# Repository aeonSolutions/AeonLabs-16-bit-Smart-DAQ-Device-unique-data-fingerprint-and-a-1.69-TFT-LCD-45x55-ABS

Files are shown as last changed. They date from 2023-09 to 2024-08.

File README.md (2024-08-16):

<p align="center">
   
</p>


 
<a href="https://github.com/sponsors/aeonSolutions">
   
</a>

**Unique Visits** <a href="https://trackgit.com"> trackgit-views </a>



 
</p>

**Navigation** | [AeonLabs Main Index](https://github.com/aeonSolutions/aeonSolutions/blob/main/aeonSolutions-Main-Index.md)  >>   [open Hardware Electronics](https://github.com/aeonSolutions/PCB-Prototyping-Catalogue)  >>  [Laboratory Automation](https://github.com/aeonSolutions/PCB-Prototyping-Catalogue/tree/main/Laboratory%20Automation)  >> Smart DAQs   >> [16-bit Smart DAQs](https://github.com/aeonSolutions/PCB-Prototyping-Catalogue/blob/main/Smart%20DAQ/16-bit/readme.md)   >>  16-bit Smart DAQ Device with unique data fingerprint and a 1.69" TFT LCD 45x55 ABS

<p align="right">
 <a href="https://github-com.translate.goog/aeonSolutions/PCB-Prototyping-Catalogue/tree/main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">Change Language</a> <br>
Last update: 11-08-2024
</p>

# 16-bit Smart DAQ Device with unique data fingerprint and a 1.69" TFT LCD 45x55 ABS
This is the repository for the 16-bit Smart DAQ Device with a unique data fingerprint able to do experimental data upload to any data repository. This specific hardware electronics utilizes the ADC IC AD5693 from Analog Devices. More information about this ADC IC [here](https://www.analog.com/en/products/ad5693.html). 

<p align="center">
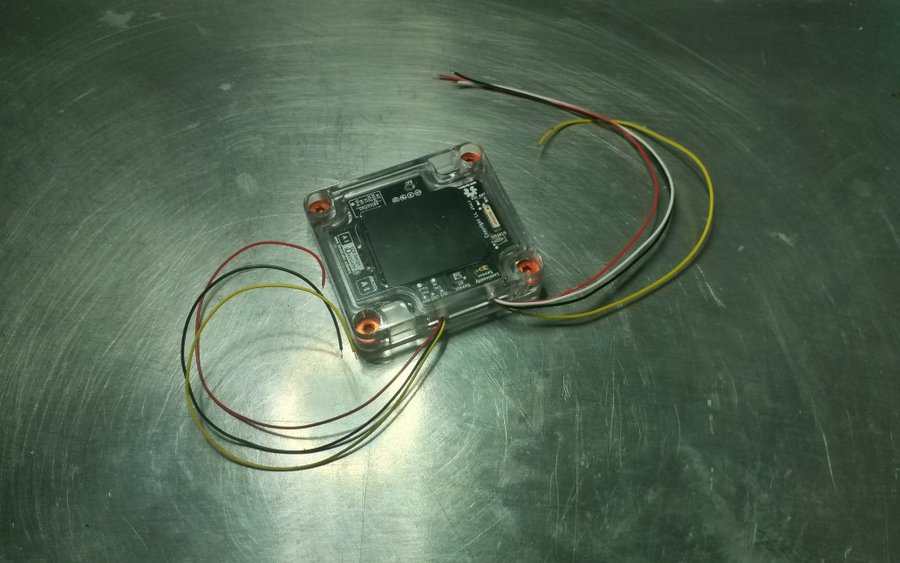
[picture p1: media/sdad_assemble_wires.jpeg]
   
</p>

<p align="center">
<strong> <a href="https://aeonsolutions.github.io/sponsor/sdad/2ch/">Interactive view of the PCB Layout</a> </strong> &nbsp;
  <strong> <a href="https://aeonsolutions.github.io/sponsor/sdad/2ch/circuit_schematic.html">Interactive view of the circuit schematic</a> </strong> <br>
 <sup>Click to view the latest revision</sup>
</p>

<br>

### rev. 10-2024
status: being designed in KiCad <br>
Known Issues: <br>
- ..

<p align="center">
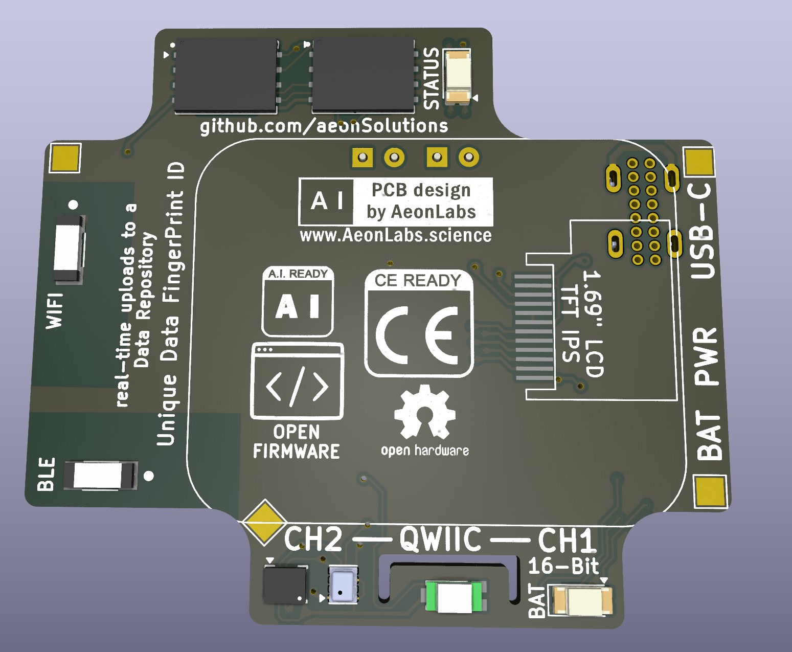
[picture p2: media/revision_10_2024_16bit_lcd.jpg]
    
</p>

<br>

### rev. 10-2023
status: Fully working <br>
Known Issues: <br>
- PCB copper track optimizations
- components rearrangement for optimization of PCB track inductance 

<p align="center">
    
</p>

### rev. 03-2024
This hardware electronics revision has major improvements in the power supply and  also power management improving immensely battery life. It also features USB-C to serial UART communications.

status: Fully working <br>
Known Issues: <br>
- PCB copper track optimizations
- components rearrangement for optimization of PCB track inductance
- poor design of the ground plane on the power management zone of the PCB
- The ultra-deep sleep power management does not work as intended. This is now solved in revision 05-2024.

<p align="center">
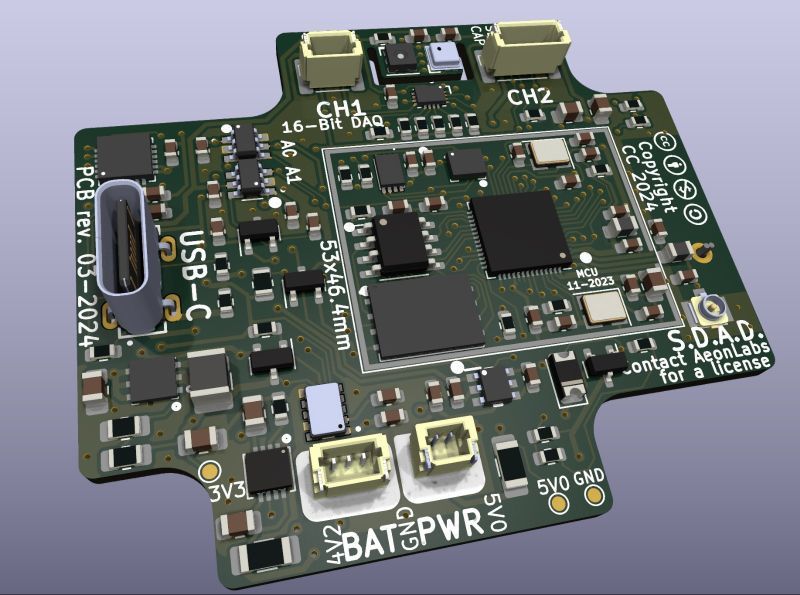
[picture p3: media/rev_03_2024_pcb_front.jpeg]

</p>

<br>
<br>

The photo below is one of the many specimens I purposely fabricated to research the self-sensing properties of asphalt mixed with a known content of carbon fibers. This is a 10cm cylinder specimen and on the top is already set up my own design smart #DAQ (get it here on my GitHub ) with the ability to upload LIVE experimental data to a #dataverse. The smart DAQ is installed on an acrylic case and screwed with plastic screws to an acrylic base with the same cross-section area as the specimen to be tested. 

The acrylic base can be bought [here](https://s.click.aliexpress.com/e/_DEGsZaL). And the acrylic case [here](https://s.click.aliexpress.com/e/_Dmudkjt). 

<p align="center">
  
</p>

<br>

## Dataverse API C library

This device uses my C++ library to expedite dataverse API integration on smart DAQ devices or elsewhere. Follow the link to its repository:

https://github.com/aeonSolutions/OpenScience-Dataverse-API-C-library

<p align="center">
<a href="https://github.com/aeonSolutions/OpenScience-Dataverse-API-C-library"> 
    
</a> 
</p>

## CE Ready Logo
This hardware is ready to get a CE marking. To learn more about this marking goto to [Wikipedia here](https://en.wikipedia.org/wiki/CE_marking).

<p align="center">
   
</p>

<br>

### Sponsor Open Hardware Solutions 
AeonLabs invests time and resources in providing this open-source hardware electronics. <br>
Did you like any of my PCB KiCad Designs? Help and Support my open work by becoming a GitHub sponsor. Starts with only $1 / 1€.

<p align="center">
    <a href="https://github.com/aeonSolutions/PCB-Prototyping-Catalogue/blob/main/become_a_sponsor/aeonlabs-github-sponsorship-agreement.docx">
        
    </a>
    <a href="https://github.com/sponsors/aeonSolutions">
        
    </a>
</p>

<br>

### Smart PCB Hardware Specifications
The hardware specifications for this 16-bit PCB with dimensions of 23.5x43.5mm can be found [here](https://github.com/aeonSolutions/openScience-Smart-DAQ-to-Upload-Live-Experimental-Data-to-a-Data-Repository/wiki/16‐bit-Smart-DAQ-Hardware-Specifications).

<br>
<br>

 **In real life this smart DAQ is able to:**
- connect to all kinds of 3V to 5V Digital sensors;
- connect to all kinds of sensors compatible with the I2C protocol. (max 118 sensors simultaneously)
- measure voltage in the range of  [0;3.3V]
- measure electrical resistance [0; 10^6] Ohm 
- do temperature and humidity compensation on all measurements 
- has a voltage reference sensor for improved accuracy on ADC measurements  
- has a motion sensor to know if anyone moved a specimen during an experiment
- ability to show live experimental data on the 1.69-inch TFT IPS LCD  

<br>
<br>

## PCB circuit Schematic 
The PCB circuit schematic is available in PDF located in the folder "PCB Schematic"
<br>

## PCB design files
The PCB KiCad files are located in the folder "KiCad" 

<br>
<br>

## Proof of Concept

To test and validate proposed smart DAQ PCB electronics and its firmware as a solution for LIVE experimental data measurements on any test specimen part of an experimental campaign, This PCB electronics is being used to measure a predefined set of variables/parameters to further study several asphalt mixtures with known carbon fiber weight content in the asphalt matrix. Below is a YouTube link to an unedited short video showing one of the experimental setups.

<p align="center">
    <a href="ttps://youtu.be/eOA1JPgop0kh">
       
    </a>
</p>

<br />
<br />

## Author

You can get in touch with me on my LinkedIn Profile:

#### Miguel Tomas



<a href="https://stackexchange.com/users/18907312/miguel-silva">profile for Miguel Silva on Stack Exchange, a network of free, community-driven Q&A sites</a>



You can also follow my GitHub Profile to stay updated about my latest projects: 

<br>

**Hire me** <br>
See [here](https://github.com/aeonSolutions/PCB-Prototyping-Catalogue/wiki/How-to-Hire-AeonLabs) how to hire AeonLabs.

<br>

### Be supportive of my dedication and work towards technology education and buy me a cup of coffee
The PCB design Files I provide here for anyone to use are free. If you like this Smart Device or use it, please consider buying me a cup of coffee, a slice of pizza or a book to help me study, eat and think new PCB design files.

<p align="center">
    <a href="https://www.buymeacoffee.com/migueltomas">
        
    </a>
</p>

### Make a donation on PayPal
Make a donation on PayPal and get a TAX refund*.

<p align="center">
    <a href="http://paypal.me/mtpsilva">
        
    </a>
</p>

### Support all these open hardware projects and become a GitHub sponsor  
Did you like any of my PCB KiCad Designs? Help and Support my open work to all by becoming a GitHub sponsor.

<p align="center">
    <a href="https://github.com/aeonSolutions/PCB-Prototyping-Catalogue/blob/main/become_a_sponsor/aeonlabs-github-sponsorship-agreement.docx">
        
    </a>
    <a href="https://github.com/sponsors/aeonSolutions">
        
    </a>
</p>

### License

Before proceeding to download any of AeonLabs open source code for software solutions and/or open hardware electronics for smart devices and data acquisition make sure you are choosing the right license for your project. See [AeonLabs Solutions for Open Hardware & Open Source Code](https://github.com/aeonSolutions/PCB-Prototyping-Catalogue/wiki/AeonLabs-Solutions-for-Open-Hardware-&-Source-Development) for more information. For commercial business solutions contact AeonLabs for more information ℹ️ using the contacts above. Thank you 🙏.

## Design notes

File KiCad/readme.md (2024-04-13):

[PCB-Prototyping-Catalogue](https://github.com/aeonSolutions/PCB-Prototyping-Catalogue)  >>  [Laboratory Automation](https://github.com/aeonSolutions/PCB-Prototyping-Catalogue/tree/main/Laboratory%20Automation)  >> S.D.A.D.

<div align="right">
 <a href="https://github-com.translate.goog/aeonSolutions/AeonLabs-AI-Volvo-MKII-Open-Hardware/wiki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">Change language</a>  <br>
Last change 13-04-2024
</div>

<br>

This folder contains the KiCad Project files for the Smart Data Acquisition Device, the S.D.A.D.,  used on my Open Science projects. Each KiCad project is available with a [creative commons share alike non-commercial license](https://creativecommons.org/licenses/by-nc-sa/4.0/deed.en) . 

<p align="center">
  <strong> <a href="https://aeonsolutions.github.io/portfolio/hardware_electronics/laboratory/">Interactive web view of the PCB Layout</a> </strong> <br>
 <sup>Click to view the latest revision of the PCB Layout</sup>
</p>

However, they're not fully complete. If you like it and are looking to use it on your projects, you can download the complete Kicad project files with a one-time donation, [click here](https://github.com/sponsors/aeonSolutions) to learn how,  and don't forget to include it in a message the name of the module/hardware electronics you need. <br> Thank you 🙏.

### Support all these open hardware projects and become a GitHub sponsor  
Did you like any of my PCB KiCad Designs? Help and Support my open work to all by becoming a GitHub sponsor.

<p align="center">
    <a href="">
        
    </a>
    <a href="https://github.com/sponsors/aeonSolutions">
        
    </a>
</p>

#

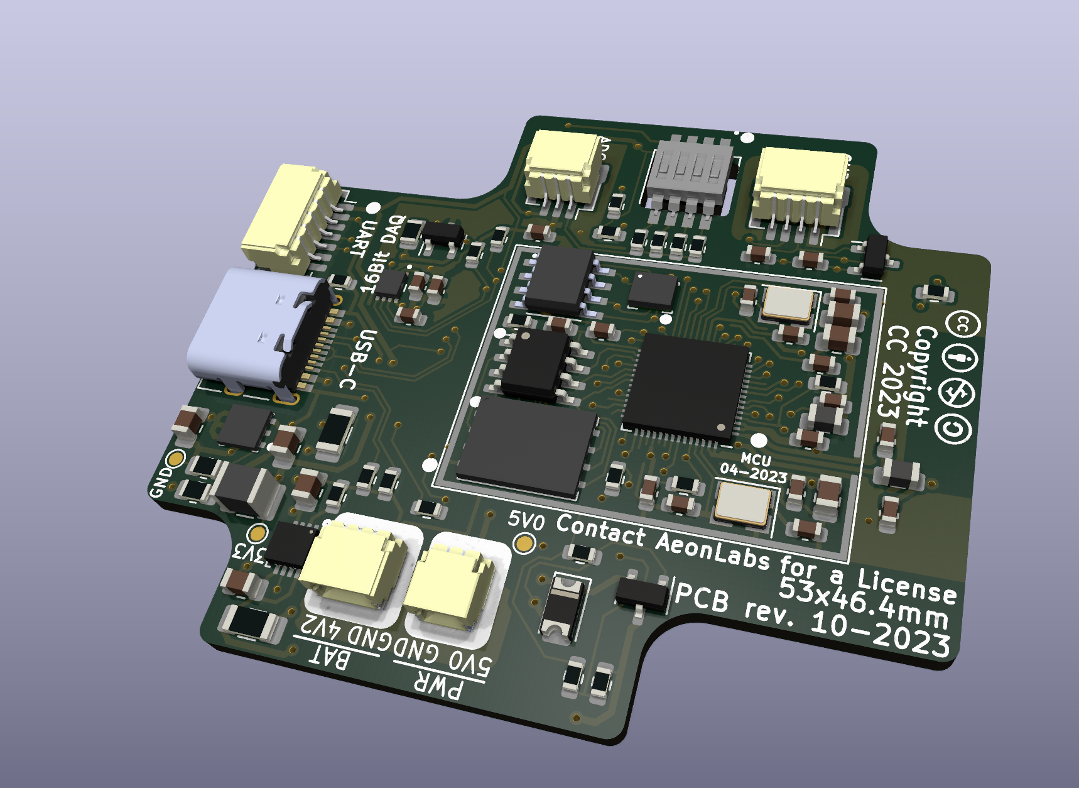
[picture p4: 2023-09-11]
media/pcb_front.png

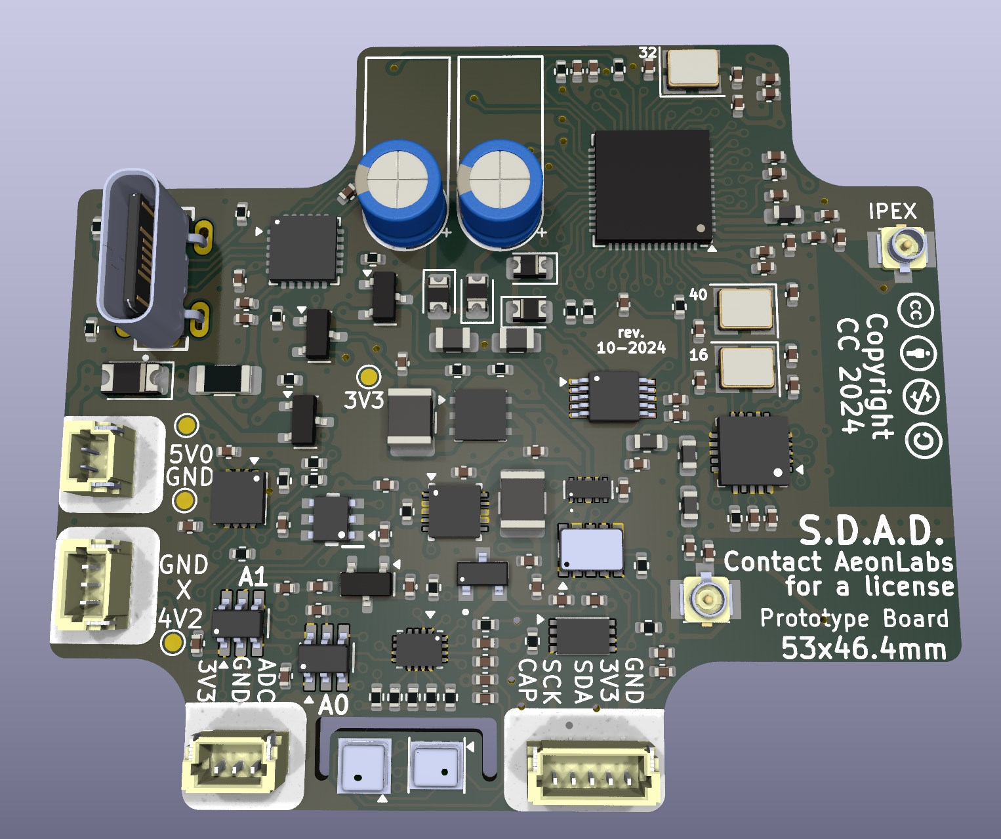
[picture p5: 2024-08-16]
media/revision_10_2024_16bit.jpg

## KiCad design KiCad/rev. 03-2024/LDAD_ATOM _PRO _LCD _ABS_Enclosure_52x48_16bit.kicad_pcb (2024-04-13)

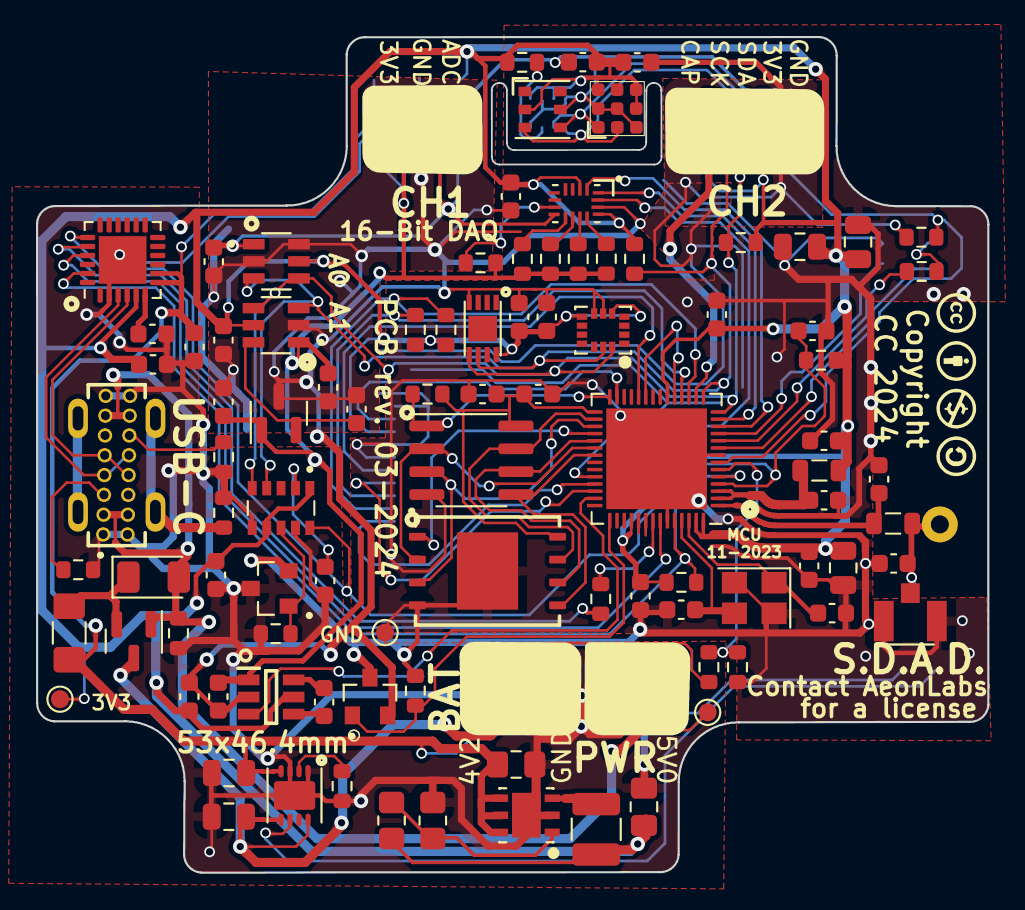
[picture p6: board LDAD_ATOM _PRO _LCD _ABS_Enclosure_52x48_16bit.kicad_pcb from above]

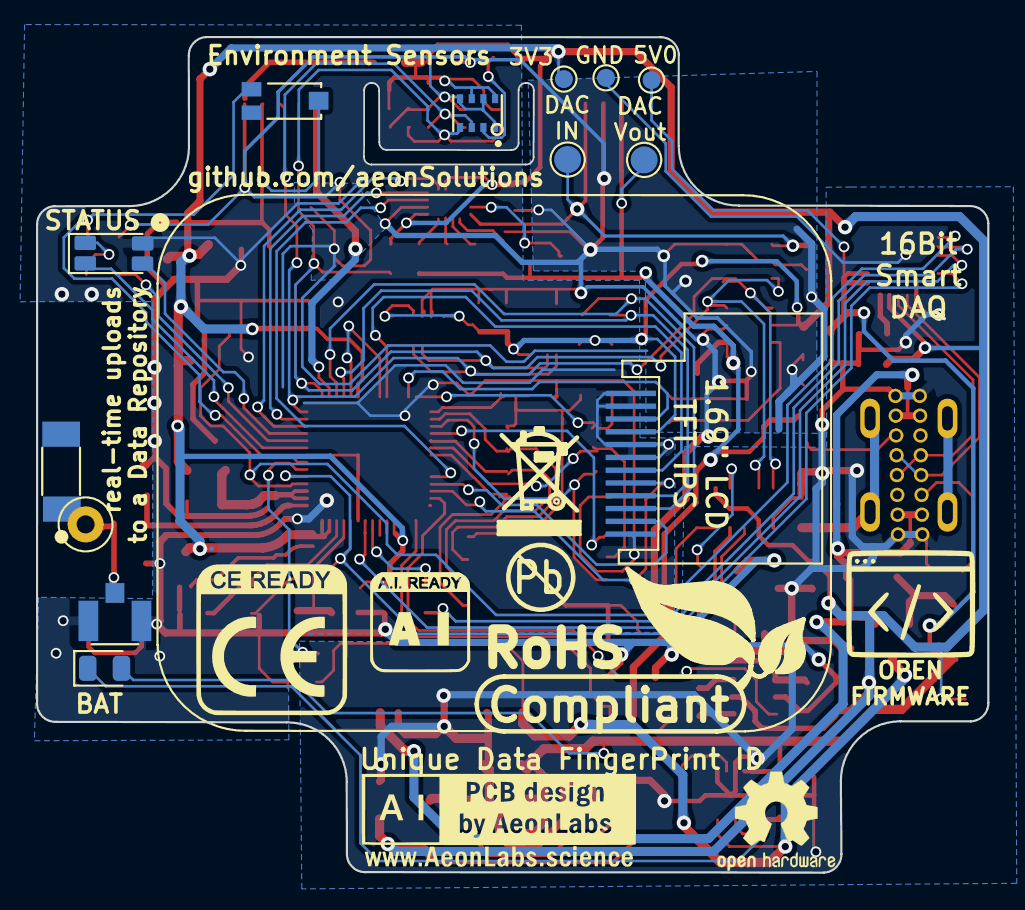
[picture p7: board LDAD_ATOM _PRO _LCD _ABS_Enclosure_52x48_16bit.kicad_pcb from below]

Board: 2 copper layers, 52.9 x 46.4 mm, 111 parts (13 on the bottom side), 70 nets.

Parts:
ADS1100_CH1, ADS1100_CH2: ADS1100A0IDBVR; ADS1100 16-bit ADC SOT95P280X145-6N
ADS1100_CH_C1, ADS1100_CH_C3: 33-100pF; C_0603_1608Metric
ADS1100_CH_C4: 100nF; C_0603_1608Metric
ATSHA_C1: 100nF; C_0603_1608Metric
AUR1: AUR9718x_DFN_3x3mm_6_pin; AUR9718 ST1S09 SON95P300X300X100-7N
AUR_C1: 22uF; C_0805_2012Metric_Pad1.18x1.45mm_HandSolder
AUR_C2: 4.7uF; C_0805_2012Metric_Pad1.18x1.45mm_HandSolder
AUR_R1: 75k; R_0805_2012Metric_Pad1.20x1.40mm_HandSolder
AUR_R2: 24k; R_0805_2012Metric_Pad1.20x1.40mm_HandSolder
AUR_l1: 3.3uF; L_1210_3225Metric
BAT_SENSE_R1, BAT_SENSE_R2: 100k; R_0603_1608Metric
BMPR1: 10k; R_0603_1608Metric
CHC1, CHC2, CHC3: 1uF; C_0603_1608Metric
CN3065_C2: 4.7uF; C_0805_2012Metric
CN3065_R1: 1K8; R_0603_1608Metric
CN3065_STDBY_LED1: LED; LED_0805_2012Metric
CN3965_C1: 22uF; C_0805_2012Metric
DIP_R1: 4k7; R_0603_1608Metric
DIP_R2: 1k; R_0603_1608Metric
DIP_R3: 20k; R_0603_1608Metric
DIP_R4: 200k; R_0603_1608Metric
DIP_R5: 2M; R_0603_1608Metric
DMP1045U_1: DMP1045U; SOT-23
DMP1045_R1: 10K; R_0603_1608Metric
DMP1045_SCHOT1: D_Schottky; D_1206_3216Metric
ENS_C1: 1uF; C_0603_1608Metric
ENS_C2: 100nF; C_0603_1608Metric
EPS1: ESP32-PSRAM_LY68L6400S; SOIC-8_3.9x4.9mm_P1.27mm
ESP32S1: ESP32-S3; QFN-56-1EP_7x7mm_P0.4mm_EP5.6x5.6mm
ESP_FLASH1: W25Q128JVS; WSON8 FLASH SPI SON127P800X600X80-9N
E_DTR_R1: 10k; R_0603_1608Metric
E_LNA_ANT1: SMD-BUILT-IN-ANTENNA-2.4GHZ(2P-9.5X2.1MM); CrossAir CA-C03
E_LNA_ANT2, E_LNA_ANT2#2: U.FL-R-SMT(01); RF Antenna IPEX SMD PCB HRS_U.FL-R-SMT(01)
E_LNA_C1, E_LNA_C2: 2.7pF; C_0603_1608Metric
E_LNA_l1: 1.8nH 5%; L_0805_2012Metric
E_RTS_C1: 100nF; C_0603_1608Metric
E_RTS_R1: 10k; R_0603_1608Metric
E_SPI_C1: 1uF 10% 50V; C_0603_1608Metric
E_SPI_C2: 100nF 10% 16V; C_0603_1608Metric
E_UART_TX_1: 499R; R_0603_1608Metric
E_VDDA_C1: 100nF; C_0603_1608Metric
E_VDDA_C2: 1uF 10% 50V; C_0805_2012Metric
E_VDD_3_C1, E_VDD_3_C2: 10uF 20% 6.3V; C_0805_2012Metric
E_VDD_3_C3, E_VDD_3_C4: 100nF 10% 16V; C_0603_1608Metric
E_VDD_CPU_C1: 100nF 10% 16V; C_0603_1608Metric
E_VDD_L1: 12nH 5%; L_0805_2012Metric
E_VDD_RTC_C1: 100nF 10% 16V; C_0603_1608Metric
E_XTAL40_1: 40Mhz 22pF+-10PPM; Crystal_SMD_3225-4Pin_3.2x2.5mm
E_XTAL40_C1, E_XTAL40_C2: 22pF 5% 50V; C_0603_1608Metric
ExtSWBAT_PLUG2: Conn_01x03_Female; JST_SH_BM03B-SRSS-TB_1x03-1MP_P1.00mm_Vertical
HXC1, HXC2, HXC3: 2.2uF; C_0603_1608Metric
I2C_SCL_R1, I2C_SCL_R2, I2C_SDA_R1, I2C_SDA_R2: 10k; R_0603_1608Metric
IC1: HX4002; HX4002 SOT95 P280X125-6N
IC_ENS1: ENS160 Gas Semsor
IMU1: LSM6DS3; LSM6DS3 Motion Sensor PQFN50P300X250X86-14N
IMUC1: 100nF; C_0603_1608Metric
J2: USB4120-03-C_REVA; USB-C Vertical GCT_USB4120-03-C_REVA
LCD1: Conn_01x12_Male; 1,69 inch LCD IPS TFT
LED1: LED_GBRC; LED_1206_3210_RGB_Metric
LR1: 330R; R_0603_1608Metric
NPN1, NPN2: NPN & PNP SOT-23
NPN1R1, NPN1R3: 10k; R_0603_1608Metric
PLUG1: PLUG1; JST_SH_BM03B-SRSS-TB_1x03-1MP_P1.00mm_Vertical
PLUG2: PLUG2; JST_SH_BM05B-SRSS-TB_1x05-1MP_P1.00mm_Vertical
PSRAM_R1: 100K; R_0603_1608Metric
PWR_FUSE1: Polyfuse; Fuse_1206_3216Metric_Pad1.42x1.75mm_HandSolder
PWR_PLUG1: Screw_Terminal_01x02; JST_SH_BM02B-SRSS-TB_1x02-1MP_P1.00mm_Vertical
RV_C1, RV_C2: 47pF; C_0603_1608Metric
Sign-PbFree: LOGO_PBFREE
Sign-RecycleBin: LOGO_RECYCLEBIN_1
Sign-RoHS: LOGO_ROHS_1
TMPR1: 10K; R_0603_1608Metric
TMUX_C1: 100nF; C_0603_1608Metric
TP1, TP1#2: VIN; TestPoint_Pad_D1.0mm
TP2, TP2#2: VOut; TestPoint_Pad_D1.0mm
TP3, TP3#2: GND; TestPoint_Pad_D1.0mm
U1: MCP1525-TT; SOT-23
U2: ATSHA204A-MAHDA-T; ATSHA204A-MAHDA-T UDFN-8
U3: Battery_charger_CN3065_QFN8; CN3065
U4: AHT20; AHT20 HT Sensor PSON100P300X300X110-6N
U5: CH9102F
U6: TEMT6000; TEMT6000-SEN
U7: BMP280; XDCR_BMP280
U8: TMUX1108RSVR; TMUX1108 1208 multiplexer QFN40P260X180X55-16N
U9: RV-1805-C3_Power_Gating; IC_RV-1805-C3 Power Gating
USB_PLUG_R2, USB_PLUG_R4: 5k1; R_0603_1608Metric
USB_PLYG_R1: 150K; R_0603_1608Metric
VOLTAGE_REF_C1, VOLTAGE_REF_C2: 100nF; C_0603_1608Metric

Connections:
3V3: ADS1100_CH1.5 (VDD), ADS1100_CH2.5 (VDD), ADS1100_CH_C4.2, ATSHA_C1.2, AUR_C1.1, AUR_R1.1, AUR_l1.1, BMPR1.2, CHC3.1, ENS_C1.2, ENS_C2.2, ESP32S1.20 (VDD3P3_RTC), ESP32S1.46 (VDD3P3_CPU), ESP32S1.55 (VDDA), ESP32S1.56 (VDDA), E_DTR_R1.1, E_RTS_R1.1, E_VDDA_C1.2, E_VDDA_C2.2, E_VDD_3_C1.1, E_VDD_3_C2.1, E_VDD_3_C3.1, E_VDD_CPU_C1.1, E_VDD_L1.1, E_VDD_RTC_C1.1, HXC2.2, I2C_SCL_R1.1, I2C_SCL_R2.1, I2C_SDA_R1.2, I2C_SDA_R2.2, IC1.5 (VIN), IC_ENS1.4 (VDD), IC_ENS1.5 (VDDIO), IC_ENS1.7 (CS), IMU1.5 (VDDIO), IMU1.8 (VDD), IMUC1.2, LCD1.4, PLUG2.2, RV_C1.2, TMUX_C1.2, TP2.1, TP2#2.1, U2.8 (VCC), U4.2 (VDD), U5.5 (VIO), U6.COLLECTOR, U7.6 (VDDIO), U7.8 (VDD), U8.2 (EN), U8.13 (VDD), U9.1 (VDD), U9.7 (VBACKUP)
3V3_PLUG: ADS1100_CH2.1 (VIN+), ADS1100_CH_C3.2, DIP_R1.2, DIP_R2.1, DIP_R3.1, DIP_R4.1, DIP_R5.2, HXC3.1, IC1.1 (VOUT), PLUG1.3, U1.1 (Vin), VOLTAGE_REF_C1.2
ADC_CH_V+: ADS1100_CH1.1 (VIN+), ADS1100_CH_C1.2, PLUG1.1, U8.8 (D)
BAT_SENSE_IO21: BAT_SENSE_R1.1, BAT_SENSE_R2.2, ESP32S1.6 (GPIO1/ADC1_CH0)
CAPACITIVE_SENSOR_IO11: ESP32S1.16 (GPIO11/ADC2_CH0), PLUG2.5
CH1_PWR_EN_3V3_IO36: ESP32S1.41 (GPIO36), IC1.3 (EN)
CHIP_EN: ESP32S1.4 (CHIP_PU/RESET), E_RTS_C1.2, E_RTS_R1.2, U5.19 (RTS), U9.10 (~RST)
DAC_CALIBRATION: ESP32S1.19 (GPIO14/ADC2_CH3), ESP32S1.23 (GPIO17/ADC2_CH6/DAC_2)
ESP_GPIO0_BOOT-DTR: ESP32S1.5 (GPIO0/BOOT), ESP32S1.52 (GPIO46), E_DTR_R1.2, U5.23 (DTR)
GND: BAT_SENSE_R1.2, EPS1.4 (VSS), ESP32S1.8 (GPIO3/ADC1_CH2), ESP32S1.51 (GPIO45), ESP32S1.57 (GND), ESP_FLASH1.4 (GND), ESP_FLASH1.9 (GND), E_LNA_ANT2.1 (GND), E_LNA_ANT2.2 (GND), E_LNA_ANT2#2.1 (GND), E_LNA_ANT2#2.2 (GND), E_LNA_C1.2, E_LNA_C2.2, E_RTS_C1.1, E_SPI_C1.2, E_SPI_C2.2, E_VDDA_C1.1, E_VDDA_C2.1, E_VDD_3_C1.2, E_VDD_3_C2.2, E_VDD_3_C3.2, E_VDD_3_C4.2, E_VDD_CPU_C1.2, E_VDD_RTC_C1.2, E_XTAL40_1.2, E_XTAL40_1.4, E_XTAL40_C1.2, E_XTAL40_C2.2, LCD1.1, LCD1.2, LCD1.5, LCD1.6, LCD1.12, LED1.4 (K), NPN1.2, NPN1R3.1, NPN2.3, TP3.1
GNDD: ADS1100_CH1.2 (GND), ADS1100_CH1.6 (VIN-), ADS1100_CH2.2 (GND), ADS1100_CH_C1.1, ADS1100_CH_C3.1, ADS1100_CH_C4.1, ATSHA_C1.1, ENS_C1.1, ENS_C2.1, HXC2.1, HXC3.2, IC1.2 (GND), IC_ENS1.3 (MISO), IC_ENS1.8 (VSS), IC_ENS1.9 (VSS), IMU1.6 (GND), IMU1.7 (GND), IMUC1.1, NPN2.2, PLUG1.2, PLUG2.1, TMPR1.1, TMUX_C1.1, U1.3 (Vss), U2.4 (GND), U4.5 (GND), U7.1 (GND), U7.5 (SDO), U7.7 (GND), U8.14 (GND), VOLTAGE_REF_C1.1, VOLTAGE_REF_C2.1
GNDPWR: AUR1.2 (GND), AUR1.7 (GND), AUR_C1.2, AUR_C2.2, AUR_R2.2, CHC1.2, CHC2.1, CHC3.2, CN3065_C2.1, CN3065_R1.1, CN3965_C1.1, DMP1045_R1.2, ExtSWBAT_PLUG2.3, J2.A1 (GND_A), J2.A12 (GND_A__1), J2.B1 (GND_B), J2.B12 (GND_B__1), NPN1.3, NPN1R1.1, PWR_PLUG1.1, RV_C1.1, RV_C2.1, TP3#2.1, U3.1 (V_Temp), U3.3 (GND), U3.9 (GND), U5.0 (GND), U5.2 (GND), U9.6 (VSS), U9.9 (WDI), USB_PLUG_R2.2, USB_PLUG_R4.2, USB_PLYG_R1.2
GPIO8_I2C_SDA: ADS1100_CH1.4 (SDA), ADS1100_CH2.4 (SDA), ESP32S1.14 (GPIO9/ADC1_CH8), I2C_SDA_R1.1, IC_ENS1.1 (SDA), IMU1.14 (SDA), PLUG2.3, U2.5 (SDA), U4.4 (SDA), U7.3 (SDI), U9.5 (SDA)
GPIO9_I2C_SCL: ADS1100_CH1.3 (SCL), ADS1100_CH2.3 (SCL), ESP32S1.15 (GPIO10/ADC1_CH9), I2C_SCL_R1.2, IC_ENS1.2 (SCL), IMU1.13 (SCL), PLUG2.4, U2.6 (SCL), U4.3 (SCL), U7.4 (SCK), U9.4 (SCL)
LCD_CS_IO36: ESP32S1.40 (GPIO35), LCD1.8
LCD_DC_IO18: ESP32S1.24 (GPIO18/ADC2_CH7/DAC_1), LCD1.7
LCD_I2C_SCL_IO12: ESP32S1.18 (GPIO13/ADC2_CH2), I2C_SCL_R2.2, LCD1.9
LCD_I2C_SDA_IO38: ESP32S1.17 (GPIO12/ADC2_CH1), I2C_SDA_R2.1, LCD1.10
LCD_LED_IO21: ESP32S1.27 (GPIO21), LCD1.3
LCD_RST_IO37: ESP32S1.39 (GPIO34), LCD1.11
LED_B_IO05: ESP32S1.11 (GPIO6/ADC1_CH5), LED1.2 (BA)
LED_G_IO02: ESP32S1.9 (GPIO4/ADC1_CH3), LED1.1 (GA)
LED_R_IO04: ESP32S1.10 (GPIO5/ADC1_CH4), LR1.1
unnamed: AUR1.1 (FB), AUR_R1.2, AUR_R2.1
unnamed: AUR1.3 (SW), AUR_l1.2
unnamed: ESP32S1.1 (LNA_IN/RF), E_LNA_C2.1, E_LNA_l1.2
unnamed: ESP32S1.49 (U0TXD/PROG/GPIO43), E_UART_TX_1.2
unnamed: ESP32S1.2 (VDD3P3), ESP32S1.3 (VDD3P3), E_VDD_3_C4.1, E_VDD_L1.2
unnamed: ESP32S1.53 (XTAL_N), E_XTAL40_1.3, E_XTAL40_C2.1
unnamed: ESP32S1.54 (XTAL_P), E_XTAL40_1.1, E_XTAL40_C1.1
unnamed: E_LNA_ANT1.1, E_LNA_ANT2#2.3 (SIG), E_LNA_C1.1, E_LNA_l1.1
unnamed: HXC1.1, IC1.6 (C+)
unnamed: HXC1.2, IC1.4 (C-)
unnamed: J2.A5 (CC1), USB_PLUG_R2.1
unnamed: J2.B5 (CC2), USB_PLUG_R4.1
unnamed: J2.S1 (SHIELD), USB_PLYG_R1.1
unnamed: LED1.3 (RA), LR1.2
unnamed: CN3065_R1.2, U3.2 (I_SET)
unnamed: CHC2.2, U5.6 (V3)
unnamed: BMPR1.1, U7.2 (CSB)
unnamed: DIP_R1.1, U8.7 (S4)
unnamed: DIP_R2.2, U8.12 (S5)
unnamed: DIP_R3.2, U8.11 (S6)
unnamed: DIP_R4.2, U8.10 (S7)
unnamed: DIP_R5.1, U8.9 (S8)
unnamed: RV_C2.2, U9.2 (CAP_RC)
PERIPHERALS_PWR_EN_IO38: ESP32S1.43 (GPIO38), NPN1R3.2, NPN2.1
PSW_EN: NPN1.1, NPN1R1.2, U9.8 (PSW)
RXD0: ESP32S1.50 (U0RXD/PROG/GPIO44), U5.21 (TXD)
SPICLK: EPS1.6 (SCLK), ESP32S1.33 (SPICLK/GPIO30), ESP_FLASH1.6 (CLK)
SPICS0: ESP32S1.32 (SPICS0/GPIO29), ESP_FLASH1.1 (~CS)
SPICS1: EPS1.1 (~CE), ESP32S1.28 (SPI_CS1/GPIO26), PSRAM_R1.1
SPID: EPS1.5 (SiO0), ESP32S1.35 (SPID/GPIO32), ESP_FLASH1.5 (DI(IO0))
SPIHD: EPS1.7 (SIO3), ESP32S1.30 (SPIHD/GPIO27), ESP_FLASH1.7 (IO3)
SPIQ: EPS1.2 (SIO1), ESP32S1.34 (SPIQ/GPIO31), ESP_FLASH1.2 (DO(IO1))
SPIWP: EPS1.3 (SIO2), ESP32S1.31 (SPIWP/GPIO28), ESP_FLASH1.3 (IO2)
STDBY_LED_G: CN3065_STDBY_LED1.1 (K), U3.6 (LED_DONE)
TEMT6000_IO33: ESP32S1.7 (GPIO2/ADC1_CH1), TMPR1.2, U6.EMITTER
TMUX1208_A0: ESP32S1.12 (GPIO7/ADC1_CH6), U8.1 (A0)
TMUX1208_A1: ESP32S1.13 (GPIO8/ADC1_CH7), U8.16 (A1)
TMUX1208_A2: ESP32S1.38 (GPIO33), U8.15 (A2)
TXD0: E_UART_TX_1.1, U5.20 (RXD)
USB_5V0: DMP1045U_1.1, DMP1045_R1.1, DMP1045_SCHOT1.2 (A), J2.A4 (VBUS_A), J2.A9 (VBUS_A__1), J2.B4 (VBUS_B), J2.B9 (VBUS_B__1), PWR_PLUG1.2, TP1.1
USB_D+: J2.A6 (D1+), J2.B6 (D2+), U5.3 (D+)
USB_D-: J2.A7 (D1-), J2.B7 (D2-), U5.4 (D-)
VDD_SPI: EPS1.8 (VCC), ESP32S1.29 (VDD_SPI), ESP_FLASH1.8 (VCC), E_SPI_C1.1, E_SPI_C2.1, PSRAM_R1.2
VIN: AUR1.4 (VIN_SW), AUR1.5 (VIN_A), AUR1.6 (EN), AUR_C2.1, CHC1.1, CN3065_STDBY_LED1.2 (A), CN3965_C1.2, PWR_FUSE1.1, TP1#2.1, U3.4 (VIN), U5.7 (VDD5), U5.8 (VBUS)
VINF: DMP1045U_1.2, DMP1045_SCHOT1.1 (K), PWR_FUSE1.2
VIN_BAT: BAT_SENSE_R2.1, CN3065_C2.2, DMP1045U_1.3, ExtSWBAT_PLUG2.1, U3.5 (BAT+), U3.8 (FB)
VOLTAGE_REF_2.5V: ADS1100_CH2.6 (VIN-), U1.2 (Vout), VOLTAGE_REF_C2.2

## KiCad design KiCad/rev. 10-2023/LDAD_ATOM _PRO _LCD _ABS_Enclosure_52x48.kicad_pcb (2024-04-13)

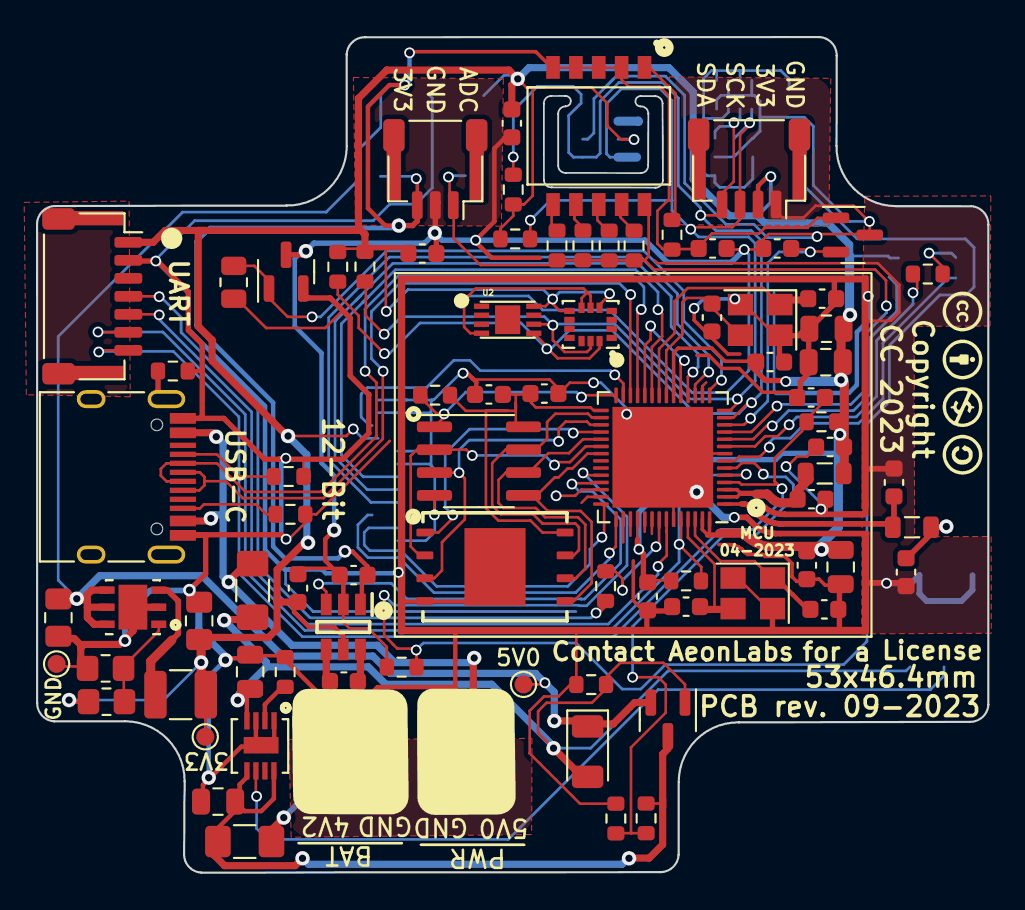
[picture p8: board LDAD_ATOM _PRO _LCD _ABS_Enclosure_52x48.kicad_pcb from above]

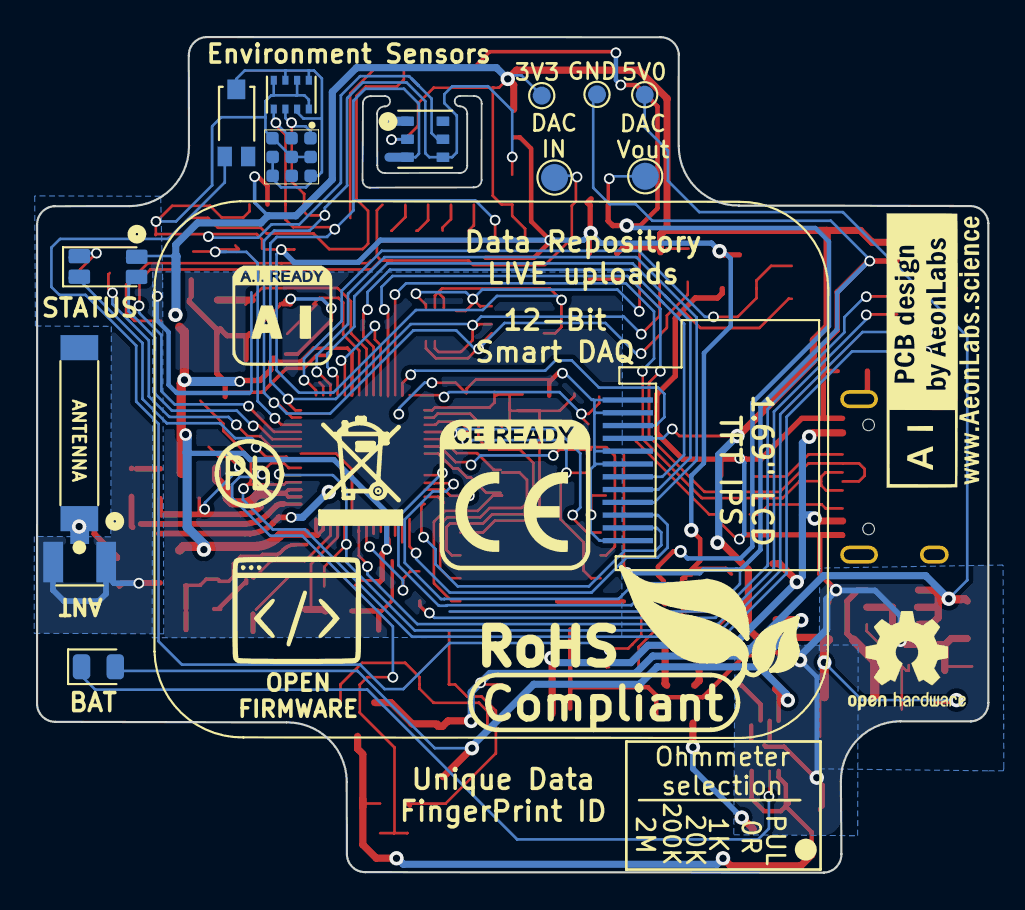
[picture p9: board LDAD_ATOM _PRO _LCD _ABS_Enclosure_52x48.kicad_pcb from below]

Board: 2 copper layers, 52.9 x 46.4 mm, 98 parts (15 on the bottom side), 64 nets.

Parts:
ATH20_C1: 100nF; C_0603_1608Metric
ATSHA_C1: 100nF; C_0603_1608Metric
AUR1: AUR9718x_DFN_3x3mm_6_pin; AUR9718 ST1S09 SON95P300X300X100-7N
AUR_C1: 22uF; C_0805_2012Metric_Pad1.18x1.45mm_HandSolder
AUR_C2: 4.7uF; C_0805_2012Metric_Pad1.18x1.45mm_HandSolder
AUR_R1: 75k; R_0805_2012Metric_Pad1.20x1.40mm_HandSolder
AUR_R2: 24k; R_0805_2012Metric_Pad1.20x1.40mm_HandSolder
AUR_l1: 3.3uF; L_1210_3225Metric
BAT_FUSE1: Polyfuse; Fuse_1206_3216Metric_Pad1.42x1.75mm_HandSolder
BAT_SENSE_R1, BAT_SENSE_R2: 100k; R_0603_1608Metric
CN3065_C2: 4.7uF; C_0805_2012Metric
CN3065_R1: 1K8; R_0603_1608Metric
CN3065_STDBY_LED1: LED; LED_0805_2012Metric
CN3965_C1: 22uF; C_0805_2012Metric
DIPSW1: Conn_02x05_Odd_Even; Dip Switch 5pin 1mm SW_DS05-127-2-06BK-SMT-TR
DIP_R1: 4k7; R_0603_1608Metric
DIP_R2: 1k; R_0603_1608Metric
DIP_R3: 20k; R_0603_1608Metric
DIP_R4: 200k; R_0603_1608Metric
DIP_R5: 2M; R_0603_1608Metric
DMP1045U_1: DMP1045U; SOT-23
DMP1045_R1: 10K; R_0603_1608Metric
DMP1045_SCHOT1: D_Schottky; D_1206_3216Metric
EPS1: ESP32-PSRAM_LY68L6400S; SOIC-8_3.9x4.9mm_P1.27mm
ESP32S1: ESP32-S3; QFN-56-1EP_7x7mm_P0.4mm_EP5.6x5.6mm
ESP32_SHIELD1: RFShield_OnePiece; ESP32-S3 GND Shield
ESP_FLASH1: W25Q128JVS; WSON8 FLASH SPI SON127P800X600X80-9N
E_DTR_R1: 10k; R_0603_1608Metric
E_LNA_ANT1: AN9520; 2.4ghZ WIFI ANTENNA AN9520_ANT2-SMD-9.5X2.1X1.0MM
E_LNA_ANT2: U.FL-R-SMT(01); RF Antenna IPEX SMD PCB HRS_U.FL-R-SMT(01)
E_LNA_C1, E_LNA_C2: 2.7pF; C_0603_1608Metric
E_LNA_l1: 1.8nH 5%; L_0805_2012Metric
E_RTS_C1: 100nF; C_0603_1608Metric
E_RTS_R1: 10k; R_0603_1608Metric
E_SPI_C1: 1uF 10% 50V; C_0603_1608Metric
E_SPI_C2: 100nF 10% 16V; C_0603_1608Metric
E_UART_TX_1: 499R; R_0603_1608Metric
E_VDDA_C1: 100nF; C_0603_1608Metric
E_VDDA_C2: 1uF 10% 50V; C_0805_2012Metric
E_VDD_3_C1, E_VDD_3_C2: 10uF 20% 6.3V; C_0805_2012Metric
E_VDD_3_C3, E_VDD_3_C4: 100nF 10% 16V; C_0603_1608Metric
E_VDD_CPU_C1: 100nF 10% 16V; C_0603_1608Metric
E_VDD_L1: 12nH 5%; L_0805_2012Metric
E_VDD_RTC_C1: 100nF 10% 16V; C_0603_1608Metric
E_XTAL32_1: 32.768Mhz 22pF+-10PPM; Crystal_SMD_3225-4Pin_3.2x2.5mm
E_XTAL32_C1, E_XTAL32_C2, E_XTAL40_C1, E_XTAL40_C2: 22pF 5% 50V; C_0603_1608Metric
E_XTAL40_1: 40Mhz 22pF+-10PPM; Crystal_SMD_3225-4Pin_3.2x2.5mm
ExtSW1: Conn_01x03_Female; JST_SH_SM03B-SRSS-TB_1x03-1MP_P1.00mm_Horizontal
ExtSWBAT_PLUG2: Conn_01x03_Female; JST_SH_SM03B-SRSS-TB_1x03-1MP_P1.00mm_Horizontal
HX1: HX4002; HX4002 SOT95 P280X125-6N
HX_C1, HX_C2, HX_C3: 2.2uF; C_0603_1608Metric
I2C_PLUG1: I2C6; JST_SH_SM04B-SRSS-TB_1x04-1MP_P1.00mm_Horizontal
I2C_SCL_R1, I2C_SDA_R1: 10k; R_0603_1608Metric
IC_ENS1: ENS160 Gas Semsor
IMR1, IMR2: 10K; R_0603_1608Metric
IMU1: LSM6DS3; LSM6DS3 Motion Sensor PQFN50P300X250X86-14N
J1: TYPE-C-31-M-12; USB_C_Receptacle_HRO_TYPE-C-31-M-12
JICSP1: Conn_01x07_Socket; JST_SH_SM07B-SRSS-TB_1x07-1MP_P1.00mm_Horizontal
LCD1: Conn_01x12_Male; 1,69 inch LCD IPS TFT
LED1: LED_GBRC; LED_1206_3210_RGB_Metric
LR1: 330R; R_0603_1608Metric
MTRR1: 10k; R_0805_2012Metric
MTRT1: NPN; SOT-23
PSRAM_R1: 100K; R_0603_1608Metric
PWR_FUSE1: Polyfuse; Fuse_1206_3216Metric_Pad1.42x1.75mm_HandSolder
PWR_PLUG1: Screw_Terminal_01x02; JST_SH_SM02B-SRSS-TB_1x02-1MP_P1.00mm_Horizontal
Sign-PbFree: LOGO_PBFREE
Sign-RecycleBin: LOGO_RECYCLEBIN_1
Sign-RoHS: LOGO_ROHS_1
TMPR1: 10K; R_0603_1608Metric
TP1, TP1#2: VIN; TestPoint_Pad_D1.0mm
TP2, TP2#2: VOut; TestPoint_Pad_D1.0mm
TP3, TP3#2: GND; TestPoint_Pad_D1.0mm
U1: MCP1525-TT; SOT-23
U2: ATSHA204A-MAHDA-T; ATSHA204 UDFN-8 DFN200X300X60-9N
U3: Battery_charger_CN3065_QFN8; QFN8 3.1x2.9mm QFNn-8 3x3 SON80P400X400X100-9N
U4: AHT20; AHT20 HT Sensor PSON100P300X300X110-6N
U5: BMP280; XDCR_BMP280
U6: TEMT6000; TEMT6000-SEN
USB_PLUG_R1, USB_PLUG_R3: 5k1; R_0603_1608Metric
USB_PLYG_R2: 150K; R_0603_1608Metric
VOLTAGE_REF_C1, VOLTAGE_REF_C2: 100nF; C_0603_1608Metric

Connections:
3V3: ATH20_C1.2, ATSHA_C1.2, AUR_C1.1, AUR_R1.1, AUR_l1.1, ESP32S1.20 (VDD3P3_RTC), ESP32S1.46 (VDD3P3_CPU), ESP32S1.55 (VDDA), ESP32S1.56 (VDDA), E_DTR_R1.1, E_RTS_R1.1, E_VDDA_C1.2, E_VDDA_C2.2, E_VDD_3_C1.1, E_VDD_3_C2.1, E_VDD_3_C3.1, E_VDD_CPU_C1.1, E_VDD_L1.1, E_VDD_RTC_C1.1, HX1.5 (VIN), HX_C3.2, I2C_PLUG1.2, I2C_SCL_R1.1, I2C_SDA_R1.2, IC_ENS1.4 (VDD), IC_ENS1.5 (VDDIO), IC_ENS1.7 (CS), IMR1.1, IMR2.1, IMU1.5 (VDDIO), IMU1.8 (VDD), JICSP1.1, LCD1.4, LED1.4 (K), TP2.1, TP2#2.1, U2.8 (VCC), U4.2 (VDD), U5.2 (CSB), U5.6 (VDDIO), U5.8 (VDD), U6.COLLECTOR
3V3_PLUG: DIPSW1.3, DIPSW1.5, DIPSW1.7, DIPSW1.9, DIP_R1.2, ExtSW1.3, HX1.1 (VOUT), HX_C1.1, U1.1 (Vin), VOLTAGE_REF_C1.2
ADC_IN_IO04: DIPSW1.2, DIP_R2.1, DIP_R3.1, DIP_R4.1, DIP_R5.1, ESP32S1.11 (GPIO6/ADC1_CH5), ExtSW1.1
BAT_SENSE_IO21: BAT_SENSE_R1.1, BAT_SENSE_R2.2, ESP32S1.6 (GPIO1/ADC1_CH0)
CHIP_EN: ESP32S1.4 (CHIP_PU/RESET), E_RTS_C1.2, E_RTS_R1.2, JICSP1.7
DAC_CALIBRATION: ESP32S1.19 (GPIO14/ADC2_CH3), ESP32S1.24 (GPIO18/ADC2_CH7/DAC_1)
ESP_GPIO0_BOOT-DTR: ESP32S1.5 (GPIO0/BOOT), ESP32S1.52 (GPIO46), E_DTR_R1.2, JICSP1.6
GND: AUR1.2 (GND), AUR1.7 (GND), AUR_C1.2, AUR_C2.2, AUR_R2.2, BAT_SENSE_R1.2, CN3065_C2.1, CN3065_R1.1, CN3965_C1.1, DMP1045_R1.2, EPS1.4 (VSS), ESP32S1.8 (GPIO3/ADC1_CH2), ESP32S1.51 (GPIO45), ESP32S1.57 (GND), ESP32_SHIELD1.1 (Shield), ESP_FLASH1.4 (GND), ESP_FLASH1.9 (GND), E_LNA_ANT2.1 (GND), E_LNA_ANT2.2 (GND), E_LNA_C1.2, E_LNA_C2.2, E_RTS_C1.1, E_SPI_C1.2, E_SPI_C2.2, E_VDDA_C1.1, E_VDDA_C2.1, E_VDD_3_C1.2, E_VDD_3_C2.2, E_VDD_3_C3.2, E_VDD_3_C4.2, E_VDD_CPU_C1.2, E_VDD_RTC_C1.2, E_XTAL32_1.2, E_XTAL32_1.4, E_XTAL32_C1.2, E_XTAL32_C2.2, E_XTAL40_1.2, E_XTAL40_1.4, E_XTAL40_C1.2, E_XTAL40_C2.2, ExtSWBAT_PLUG2.3, J1.B1, J1.B12, JICSP1.2, LCD1.1, LCD1.2, LCD1.5, LCD1.6, LCD1.12, MTRR1.1, MTRT1.2, PWR_PLUG1.1, TP3.1, TP3#2.1, U3.1 (V_Temp), U3.3 (GND), U3.9 (GND), USB_PLUG_R1.2, USB_PLUG_R3.2, USB_PLYG_R2.2
GNDD: ATH20_C1.1, ATSHA_C1.1, ExtSW1.2, HX1.2 (GND), HX_C1.2, HX_C3.1, I2C_PLUG1.1, IC_ENS1.3 (MISO), IC_ENS1.8 (VSS), IC_ENS1.9 (VSS), IMU1.6 (GND), IMU1.7 (GND), MTRT1.3, TMPR1.1, U1.3 (Vss), U2.4 (GND), U4.5 (GND), U5.1 (GND), U5.5 (SDO), U5.7 (GND), VOLTAGE_REF_C1.1, VOLTAGE_REF_C2.1
GPIO8_I2C_SDA: ESP32S1.13 (GPIO8/ADC1_CH7), I2C_PLUG1.4, I2C_SDA_R1.1, IC_ENS1.1 (SDA), IMR1.2, IMU1.14 (SDA), U2.5 (SDA), U4.4 (SDA), U5.3 (SDI)
GPIO9_I2C_SCL: ESP32S1.14 (GPIO9/ADC1_CH8), I2C_PLUG1.3, I2C_SCL_R1.2, IC_ENS1.2 (SCL), IMR2.2, IMU1.13 (SCL), U2.6 (SCL), U4.3 (SCL), U5.4 (SCK)
LCD_CS_IO13: ESP32S1.18 (GPIO13/ADC2_CH2), LCD1.8
LCD_DC_IO17: ESP32S1.23 (GPIO17/ADC2_CH6/DAC_2), LCD1.7
LCD_I2C_SCL_IO12: ESP32S1.17 (GPIO12/ADC2_CH1), LCD1.9
LCD_I2C_SDA_IO38: ESP32S1.43 (GPIO38), LCD1.10
LCD_LED_IO21: ESP32S1.27 (GPIO21), LCD1.3
LCD_RST_IO37: ESP32S1.42 (GPIO37), LCD1.11
LED_B_IO05: ESP32S1.10 (GPIO5/ADC1_CH4), LED1.2 (BA)
LED_G_IO02: ESP32S1.7 (GPIO2/ADC1_CH1), LED1.1 (GA)
LED_R_IO04: ESP32S1.9 (GPIO4/ADC1_CH3), LR1.1
unnamed: AUR1.1 (FB), AUR_R1.2, AUR_R2.1
unnamed: AUR1.3 (SW), AUR_l1.2
unnamed: DIPSW1.1, DIP_R1.1
unnamed: DIPSW1.4, DIP_R2.2
unnamed: DIPSW1.6, DIP_R3.2
unnamed: DIPSW1.8, DIP_R4.2
unnamed: DIPSW1.10, DIP_R5.2
unnamed: ESP32S1.21 (GPIO15/ADC2_CH4/XTAL_32K_P), E_XTAL32_1.3, E_XTAL32_C1.1
unnamed: ESP32S1.22 (GPIO16/ADC2_CH5/XTAL_32K_N), E_XTAL32_1.1, E_XTAL32_C2.1
unnamed: ESP32S1.1 (LNA_IN/RF), E_LNA_C2.1, E_LNA_l1.2
unnamed: ESP32S1.49 (U0TXD/PROG/GPIO43), E_UART_TX_1.2
unnamed: ESP32S1.2 (VDD3P3), ESP32S1.3 (VDD3P3), E_VDD_3_C4.1, E_VDD_L1.2
unnamed: ESP32S1.53 (XTAL_N), E_XTAL40_1.3, E_XTAL40_C2.1
unnamed: ESP32S1.54 (XTAL_P), E_XTAL40_1.1, E_XTAL40_C1.1
unnamed: E_LNA_ANT1.1, E_LNA_ANT2.3 (SIG), E_LNA_C1.1, E_LNA_l1.1
unnamed: HX1.6 (C+), HX_C2.1
unnamed: HX1.4 (C-), HX_C2.2
unnamed: J1.A5 (CC1), USB_PLUG_R3.1
unnamed: J1.B5 (CC2), USB_PLUG_R1.1
unnamed: J1.S1 (SHIELD), USB_PLYG_R2.1
unnamed: LED1.3 (RA), LR1.2
unnamed: CN3065_R1.2, U3.2 (I_SET)
PERIPHERALS_PWR_EN_IO10: ESP32S1.15 (GPIO10/ADC1_CH9), MTRR1.2, MTRT1.1
PLUG_PWR_3V3_EN_IO38: ESP32S1.39 (GPIO34), HX1.3 (EN)
RXD0: ESP32S1.50 (U0RXD/PROG/GPIO44), JICSP1.5
SPICLK: EPS1.6 (SCLK), ESP32S1.33 (SPICLK/GPIO30), ESP_FLASH1.6 (CLK)
SPICS0: ESP32S1.32 (SPICS0/GPIO29), ESP_FLASH1.1 (~CS)
SPICS1: EPS1.1 (~CE), ESP32S1.28 (SPI_CS1/GPIO26), PSRAM_R1.1
SPID: EPS1.5 (SiO0), ESP32S1.35 (SPID/GPIO32), ESP_FLASH1.5 (DI(IO0))
SPIHD: EPS1.7 (SIO3), ESP32S1.30 (SPIHD/GPIO27), ESP_FLASH1.7 (IO3)
SPIQ: EPS1.2 (SIO1), ESP32S1.34 (SPIQ/GPIO31), ESP_FLASH1.2 (DO(IO1))
SPIWP: EPS1.3 (SIO2), ESP32S1.31 (SPIWP/GPIO28), ESP_FLASH1.3 (IO2)
STDBY_LED_G: CN3065_STDBY_LED1.1 (K), U3.6 (LED_DONE)
TEMT6000_IO33: ESP32S1.38 (GPIO33), TMPR1.2, U6.EMITTER
TXD0: E_UART_TX_1.1, JICSP1.4
USB_5V0: CN3065_STDBY_LED1.2 (A), CN3965_C1.2, DMP1045U_1.1, DMP1045_R1.1, DMP1045_SCHOT1.2 (A), PWR_FUSE1.1, U3.4 (VIN)
USB_5V0F: J1.A4, J1.A9, PWR_FUSE1.2, PWR_PLUG1.2
USB_D+: ESP32S1.26 (GPIO20/USB_D+/ADC2_CH9), J1.A6 (DP1), J1.B6 (DP2)
USB_D-: ESP32S1.25 (GPIO19/USB_D-/ADC2_CH8), J1.A7 (DN1), J1.B7 (DN2)
VDD_SPI: EPS1.8 (VCC), ESP32S1.29 (VDD_SPI), ESP_FLASH1.8 (VCC), E_SPI_C1.1, E_SPI_C2.1, PSRAM_R1.2
VIN: AUR1.4 (VIN_SW), AUR1.5 (VIN_A), AUR1.6 (EN), AUR_C2.1, DMP1045U_1.2, DMP1045_SCHOT1.1 (K), TP1.1, TP1#2.1
VIN_BAT: BAT_FUSE1.1, BAT_SENSE_R2.1, CN3065_C2.2, DMP1045U_1.3, U3.5 (BAT+), U3.8 (FB)
VIN_BATF: BAT_FUSE1.2, ExtSWBAT_PLUG2.1
VOLTAGE_REF_IO07: ESP32S1.12 (GPIO7/ADC1_CH6), U1.2 (Vout), VOLTAGE_REF_C2.2

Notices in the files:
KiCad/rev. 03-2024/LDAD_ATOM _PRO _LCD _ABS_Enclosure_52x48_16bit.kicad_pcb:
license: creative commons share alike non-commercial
